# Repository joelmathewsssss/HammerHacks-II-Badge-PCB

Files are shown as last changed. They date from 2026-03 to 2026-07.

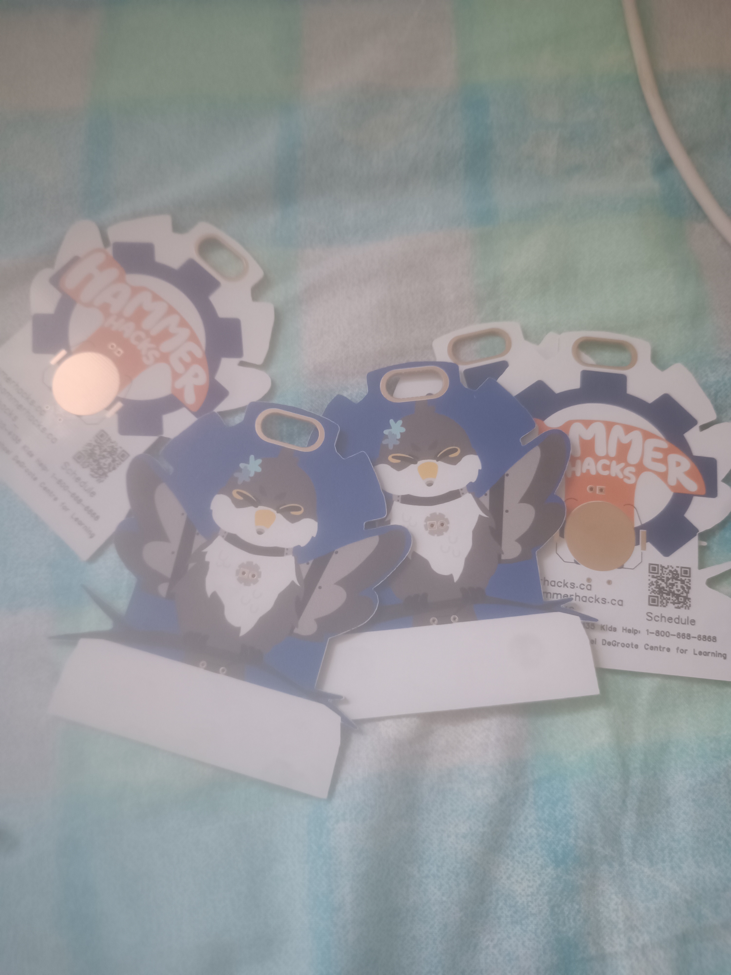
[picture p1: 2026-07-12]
assets/PICS/0ec4fcd7-279c-4da6-a28e-f8afc382110b.jpg

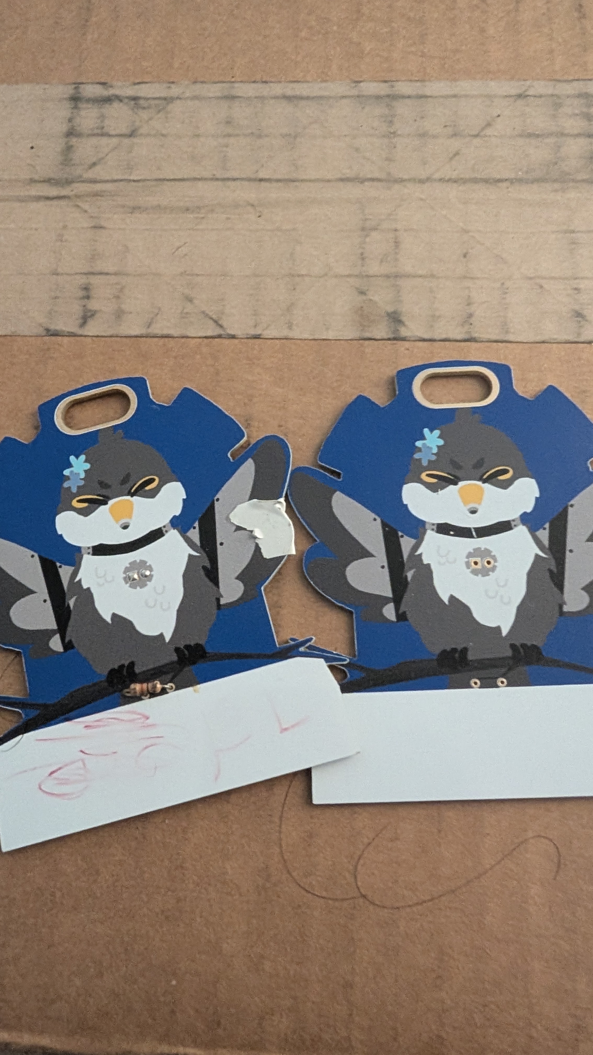
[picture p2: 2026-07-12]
assets/PICS/PXL_20260712_225921867.jpg

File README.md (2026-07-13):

# HammerHacks II Badge PCB

HammerHacks II Badge PCB

The official HammerHacks II Hacker Badge.
Made for Hackers to proudly show their name with HammerHacks swag.
Designed to be a soldering workshop to get students into hardware.
Simple PCB with LED circuit using coin battery. Includes Hackathon Info.







Demo Vid: https://drive.google.com/file/d/1kAkGNcVEJjuDBygq6s-vyhGiOASqDllP/view?usp=sharing

<table style="border-collapse: collapse; width: 100%; font-family: Arial, sans-serif; font-size: 14px">
  <thead>
    <tr>
      <th style="background-color: #f1f5f9; color: #1e293b; text-align: left; padding: 8px; font-weight: bold; border: 1px solid #e2e8f0">Name</th>
      <th style="background-color: #f1f5f9; color: #1e293b; text-align: left; padding: 8px; font-weight: bold; border: 1px solid #e2e8f0">Purpose</th>
      <th style="background-color: #f1f5f9; color: #1e293b; text-align: left; padding: 8px; font-weight: bold; border: 1px solid #e2e8f0">Quantity</th>
      <th style="background-color: #f1f5f9; color: #1e293b; text-align: left; padding: 8px; font-weight: bold; border: 1px solid #e2e8f0">Total Cost (USD)</th>
      <th style="background-color: #f1f5f9; color: #1e293b; text-align: left; padding: 8px; font-weight: bold; border: 1px solid #e2e8f0">Link</th>
      <th style="background-color: #f1f5f9; color: #1e293b; text-align: left; padding: 8px; font-weight: bold; border: 1px solid #e2e8f0">Distributor</th>
    </tr>
  </thead>
  <tbody>
    <tr>
      <td style="color: #334155; text-align: left; padding: 8px; border: 1px solid #e2e8f0">PCB Badge</td>
      <td style="color: #334155; text-align: left; padding: 8px; border: 1px solid #e2e8f0">Badge</td>
      <td style="color: #334155; text-align: left; padding: 8px; border: 1px solid #e2e8f0">1</td>
      <td style="color: #334155; text-align: left; padding: 8px; border: 1px solid #e2e8f0">8.39</td>
      <td style="color: #334155; text-align: left; padding: 8px; border: 1px solid #e2e8f0"></td>
      <td style="color: #334155; text-align: left; padding: 8px; border: 1px solid #e2e8f0">JLC PCB</td>
    </tr>
    <tr>
      <td style="color: #334155; text-align: left; padding: 8px; border: 1px solid #e2e8f0">Resistor</td>
      <td style="color: #334155; text-align: left; padding: 8px; border: 1px solid #e2e8f0">limit current</td>
      <td style="color: #334155; text-align: left; padding: 8px; border: 1px solid #e2e8f0">1</td>
      <td style="color: #334155; text-align: left; padding: 8px; border: 1px solid #e2e8f0">0.00</td>
      <td style="color: #334155; text-align: left; padding: 8px; border: 1px solid #e2e8f0"></td>
      <td style="color: #334155; text-align: left; padding: 8px; border: 1px solid #e2e8f0">Have</td>
    </tr>
    <tr>
      <td style="color: #334155; text-align: left; padding: 8px; border: 1px solid #e2e8f0">Battery:BatteryHolder_Keystone_3034_1x20mm</td>
      <td style="color: #334155; text-align: left; padding: 8px; border: 1px solid #e2e8f0"></td>
      <td style="color: #334155; text-align: left; padding: 8px; border: 1px solid #e2e8f0">1</td>
      <td style="color: #334155; text-align: left; padding: 8px; border: 1px solid #e2e8f0">4.95</td>
      <td style="color: #334155; text-align: left; padding: 8px; border: 1px solid #e2e8f0">https://www.amazon.ca/Qsvbeeqj-Battery-Retainer-Surface-Soldrable/dp/B0FLXHY725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</td>
      <td style="color: #334155; text-align: left; padding: 8px; border: 1px solid #e2e8f0">Amazon</td>
    </tr>
    <tr>
      <td style="color: #334155; text-align: left; padding: 8px; border: 1px solid #e2e8f0">Blue LED</td>
      <td style="color: #334155; text-align: left; padding: 8px; border: 1px solid #e2e8f0"></td>
      <td style="color: #334155; text-align: left; padding: 8px; border: 1px solid #e2e8f0">1</td>
      <td style="color: #334155; text-align: left; padding: 8px; border: 1px solid #e2e8f0">1.95</td>
      <td style="color: #334155; text-align: left; padding: 8px; border: 1px solid #e2e8f0">https://www.amazon.ca/100PCS-Superbright-5mm-Round-Light/dp/B00ME76D0I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</td>
      <td style="color: #334155; text-align: left; padding: 8px; border: 1px solid #e2e8f0">Amazon</td>
    </tr>
  </tbody>
</table>
Credits to Rosan Syal for making the design and Merinel Gomez for creating the assets!

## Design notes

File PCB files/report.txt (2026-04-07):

Plotted to 'C:\Users\joela\Documents\GitHub\HammerHacks II Badge PCB\PCB files\fab\HammerHacks II Badge PCB-F_Cu.gbr'.
Plotted to 'C:\Users\joela\Documents\GitHub\HammerHacks II Badge PCB\PCB files\fab\HammerHacks II Badge PCB-B_Cu.gbr'.
Plotted to 'C:\Users\joela\Documents\GitHub\HammerHacks II Badge PCB\PCB files\fab\HammerHacks II Badge PCB-F_Paste.gbr'.
Plotted to 'C:\Users\joela\Documents\GitHub\HammerHacks II Badge PCB\PCB files\fab\HammerHacks II Badge PCB-B_Paste.gbr'.
Plotted to 'C:\Users\joela\Documents\GitHub\HammerHacks II Badge PCB\PCB files\fab\HammerHacks II Badge PCB-F_Silkscreen.gbr'.
Plotted to 'C:\Users\joela\Documents\GitHub\HammerHacks II Badge PCB\PCB files\fab\HammerHacks II Badge PCB-B_Silkscreen.gbr'.
Plotted to 'C:\Users\joela\Documents\GitHub\HammerHacks II Badge PCB\PCB files\fab\HammerHacks II Badge PCB-F_Mask.gbr'.
Plotted to 'C:\Users\joela\Documents\GitHub\HammerHacks II Badge PCB\PCB files\fab\HammerHacks II Badge PCB-B_Mask.gbr'.
Plotted to 'C:\Users\joela\Documents\GitHub\HammerHacks II Badge PCB\PCB files\fab\HammerHacks II Badge PCB-Edge_Cuts.gbr'.
Created Gerber job file 'C:\Users\joela\Documents\GitHub\HammerHacks II Badge PCB\PCB files\fab\HammerHacks II Badge PCB-job.gbrjob'.
Info: Done.

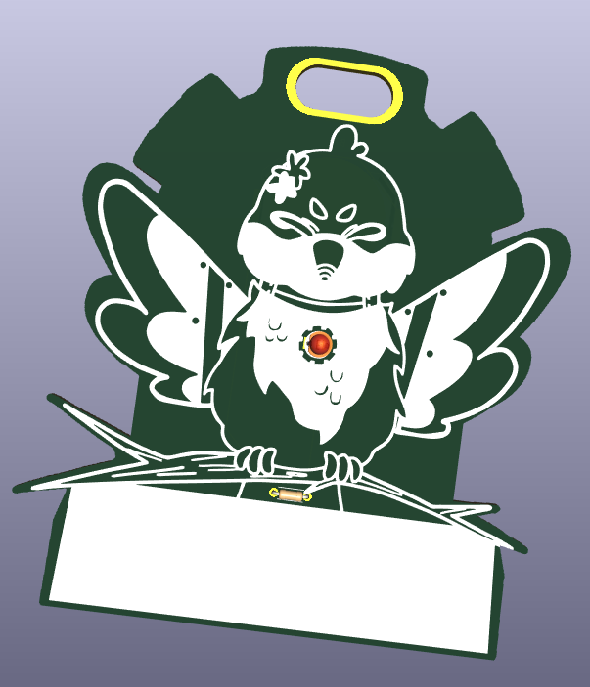
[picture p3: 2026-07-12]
assets/PICS/Screenshot 2026-03-18 171457.png

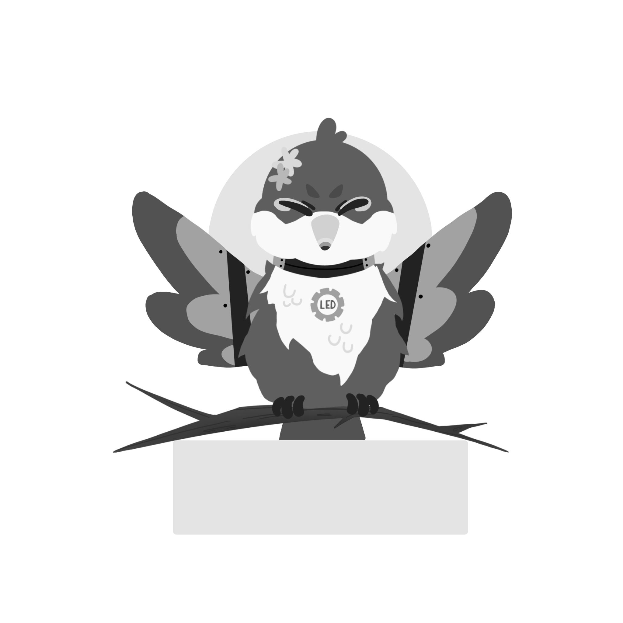
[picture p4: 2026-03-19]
assets/full.png

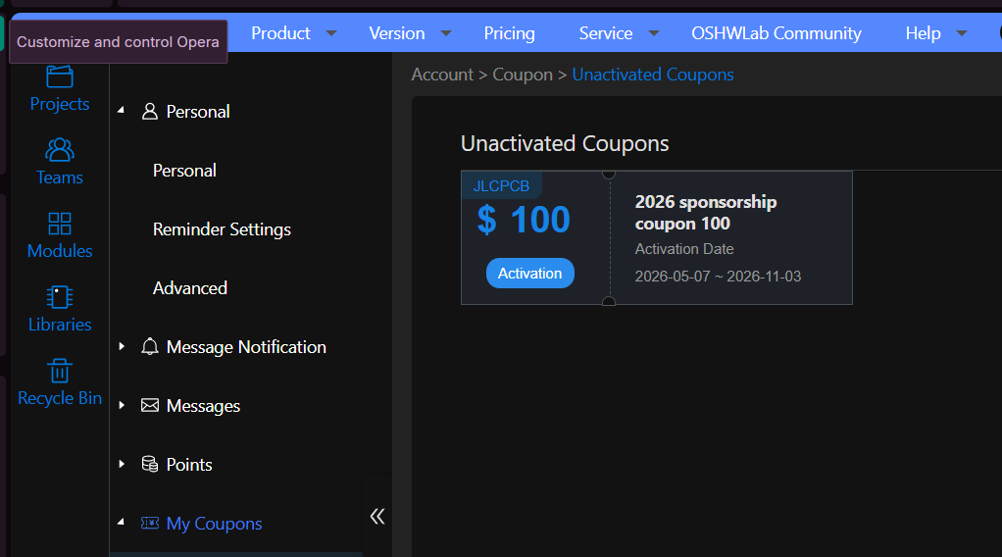
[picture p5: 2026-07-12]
assets/PICS/Screenshot 2026-05-07 062919.png

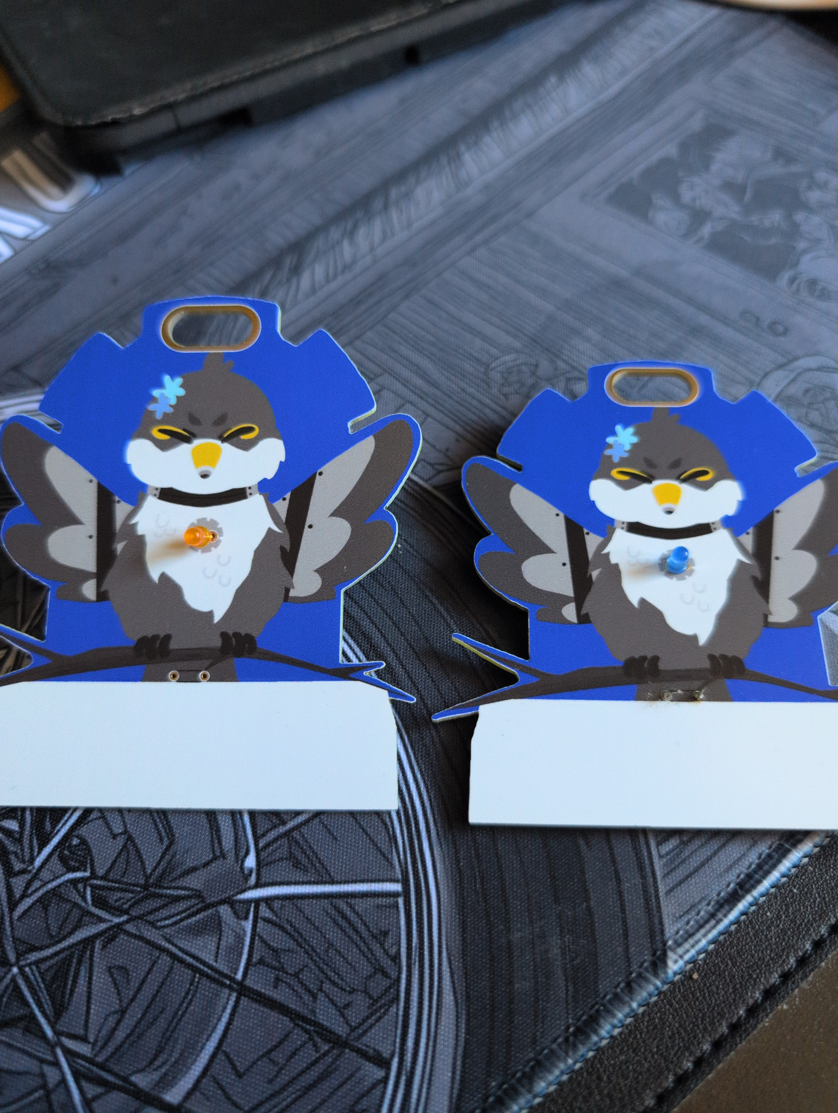
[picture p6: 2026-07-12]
assets/PICS/30e5c870-7722-40ba-a2bb-0e20258b65ed.jpg

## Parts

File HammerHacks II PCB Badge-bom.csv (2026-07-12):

Name | Purpose | Quantity | Total Cost (USD) | Link | Distributor
PCB Badge | Badge | 1 | 8.39 |  | JLC PCB
Resistor | limit current | 1 | 0.00 |  | Have
Battery:BatteryHolder_Keystone_3034_1x20mm |  | 1 | 4.95 | https://www.amazon.ca/Qsvbeeqj-Battery-Retainer-Surface-Soldrable/dp/B0FLXHY725 | Amazon
Blue LED |  | 1 | 1.95 | https://www.amazon.ca/100PCS-Superbright-5mm-Round-Light/dp/B00ME76D0I?adgrpid=1357897093534873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 | Amazon

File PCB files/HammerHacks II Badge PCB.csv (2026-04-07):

Value | Footprint | Qty | Cost | Link
Battery | Battery:BatteryHolder_Keystone_3034_1x20mm | 1 | 6.89 | https://www.amazon.ca/Qsvbeeqj-Battery-Retainer-Surface-Soldrable/dp/B0FLXHY725
LED | LED_THT:LED_D3.0mm | 1 | 2.72 | https://www.amazon.ca/100PCS-Superbright-5mm-Round-Light/dp/B00ME76D0I?adgrpid=1357897093534873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

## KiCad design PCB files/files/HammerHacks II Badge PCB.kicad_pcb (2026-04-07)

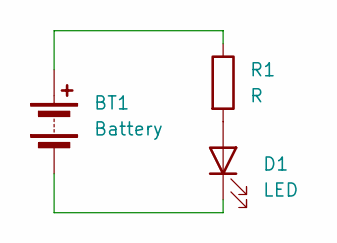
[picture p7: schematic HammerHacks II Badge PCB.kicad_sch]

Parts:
BT1: Battery; BatteryHolder_Keystone_3034_1x20mm
D1: LED; LED_D3.0mm
R1: R; R_Axial_DIN0204_L3.6mm_D1.6mm_P5.08mm_Horizontal

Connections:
unnamed: BT1.1 (+), R1.1
unnamed: BT1.2 (-), D1.1 (K)
unnamed: D1.2 (A), R1.2

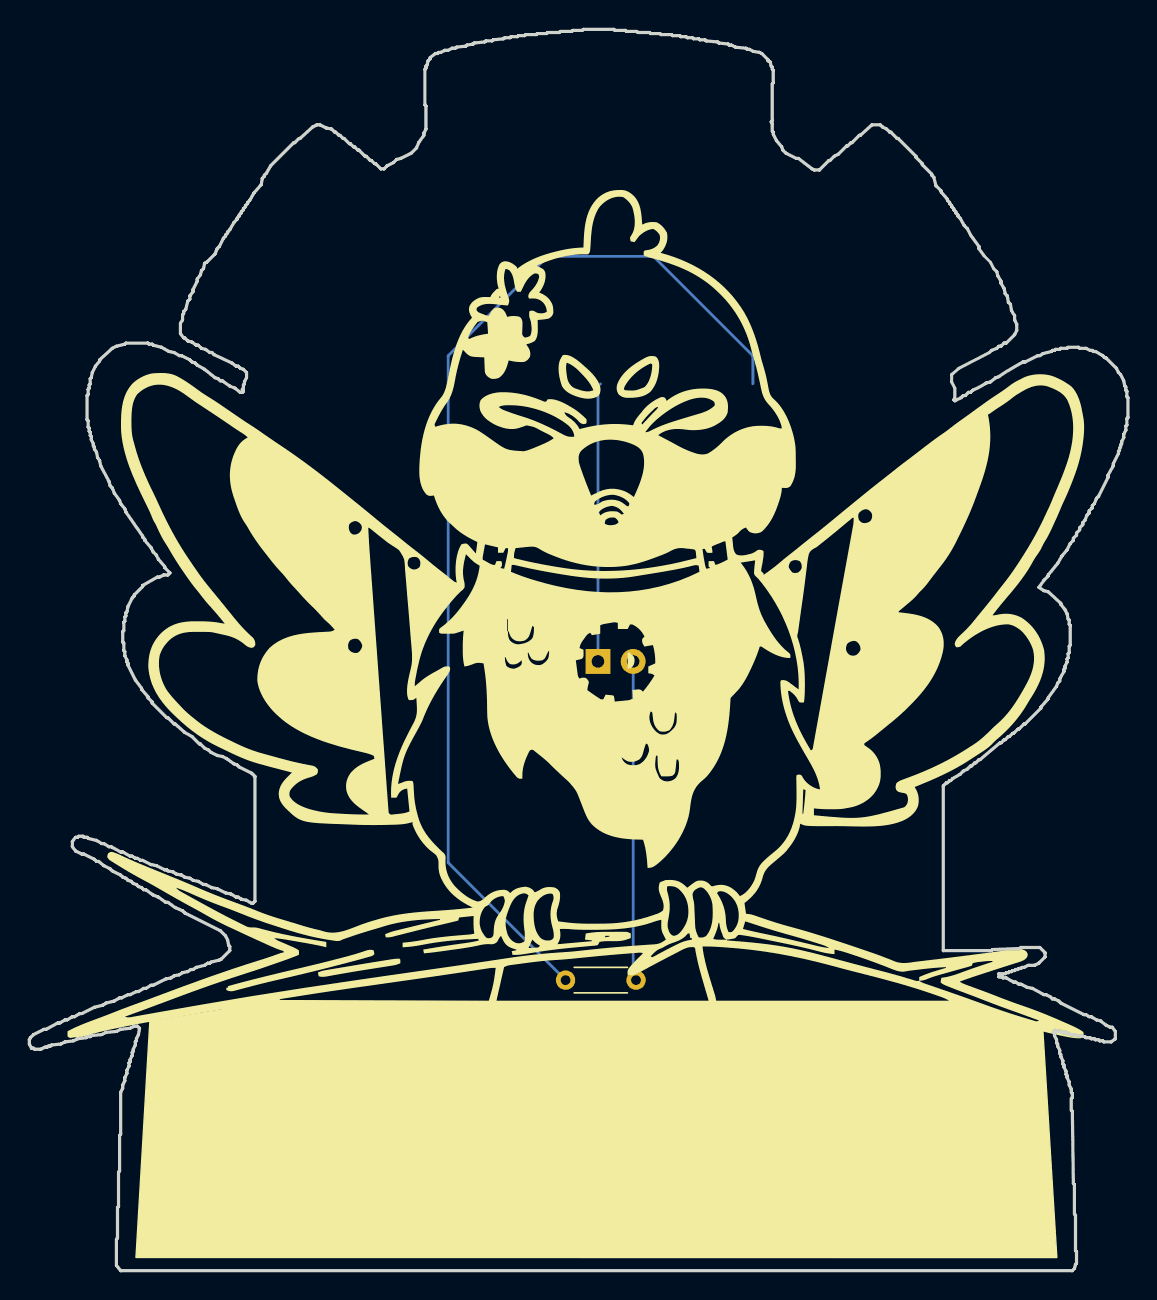
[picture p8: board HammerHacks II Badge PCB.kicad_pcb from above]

Board: 2 copper layers, 79.2 x 89.5 mm, 3 parts (1 on the bottom side), 3 nets.

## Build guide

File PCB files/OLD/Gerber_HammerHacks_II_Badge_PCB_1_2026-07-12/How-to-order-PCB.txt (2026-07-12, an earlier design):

How to Order PCB

Please refer to:
https://prodocs.easyeda.com/en/pcb/order-order-pcb/index.html

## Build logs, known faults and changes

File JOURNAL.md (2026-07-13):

<!--
  This journal is auto generated by Stasis.
-->
# Total Time Spent: 18.5h

# 7/12/2026 11 PM - Soldering up and Finishing V2

_Time spent: 0.1666666666666667h_

Finally soldered up the badge and it works!

I dont have side cutters so the wires are a bit choppy. 








# 7/12/2026 11 PM - Updating PCB for V2

_Time spent: 2.066666666666667h_

Fixed all issues identified in v1

I:

- Scaled the bird down and repositioned
- Made lanyard hole shorter
- Changed footprint to horizontal
- Changed name area slikscreen bounds
- Adjusted rear logo size and scale
- Changed CR2032 battery holder orientation for easy access
- Resized and reformated text and icons
- Fixed routing to be wired correctly

In addition, added sponsor logos to fuffil sponsorship goals










# 7/12/2026 11 PM - Soldering the first time and testing

_Time spent: 1h_

Soldered the components together.

Found that there were issues:

- Bird not centered and cut off
- Lanyard hole was too big
- Resistor Footprint was for vertical and not horizontal
- Name writing area silkscreen was too tall and cutoff tail
- Rear Logo was too big and wide
- Text was too congested and icons too thick

Most importantly, Easy EDA routed through the battery pad contacts (something I've never experienced before on KiCad), causing a short circuit that would stop the circuit from working.





30e5c870-7722-40ba-a2bb-0e20258b65ed

0ec4fcd7-279c-4da6-a28e-f8afc382110b






# 4/7/2026 2 PM - Converting to Easy EDA

_Time spent: 4.733333333333333h_

Due to sponsorship request from JLCPCB/Easy EDA, in order to get pcb discount, the pcb design had to be processed through Easy EDA Pro and use their multicolour silkscreen technology.

So I imported my KiCad project into Easy EDA and tried to fix things. I spent alot of time figuring out how to use Easy EDA as it was my first time. Spent a bunch of time trying to fix the silkscreen before I learned I could just import images.

So, I added some colour to the images, imported them, formatted the objects and added a few details (like qr code of schedule) and fixes on the back.

Spent time going through the fabrication process.











# 3/19/2026 4 AM - Grinding out Design Onto PCB

_Time spent: 6h_

Watch the timelapse instead- https://lapse.hackclub.com/timelapse/TLW3UozBr5oJ

Transformed design outline into edgecut
It was alot faster this time from the practice and learning from making a rough design, I knew how to use the online tools and where it breaks (see where I manually have to fix the edgecut)

Added design silk screen

Changed led from neopixel to normal and circuit to only have one LED.
Talked with the team and we decided to change to normal leds, as they look better and are easier to solder. I also spent alot of time looking at components, for what to order, how much it costs to order in bulk (since these badges will be for hackathon participants (about 150))

If youre making a PCB design, please get the Transformit plugin, (https://openscopeproject.org/projects/transformit/) saves lives.

Added silkscreen area to write name.
At first it was too small (4.2x1.4cm), so I resized (using transformit) (to 6.7cm x 1.8 cm)

Made a hole footprint in badge to attatch lanyard.

Added front copper layer design highlights.
At first, I was really dumb and did it manually. Next time i just used ms paint to fill in sections.

Added title text with back copper layer
Tried a couple things with text and canva but it didnt really work so I just added the logo text (from when I made a rough design (yes it was useful!)) on the back

Added (then removed) team signatures to rear silkscreen

Added org, event and safety info to rear silkscreen.

Results:














# 3/18/2026 6 PM - Designing PCB rough (waiting for good)

_Time spent: 4.5h_

Circuit - Design simple LED circuit to start in new KiCad Project:



Footprints - doing research for potential parts for pcb badge and assigning footprints. Decided to power pcb with CR2032 coin battery, 220 Ω throughole resistors and SMD 0805 (2mm x 1.2mm) Blue for LEDs:



Making PCB - Took the most time since I had to figure out how to make a custom pcb edge cut. I started by trying to trace a refrence image but it was too off/took too much time. I decided to try png to svg converters, went through a couple different tools (https://www.freeconvert.com/png-to-svg,https://pdfaid.com/svg-to-dxf,https://convertio.co/svg-dxf/,https://www.ilovesvg.com/image-to-svg-outline) until I found the one (https://fiveko.com/online-tools/picture-outline/). I had to try a couple times before I got the right shape and outline. Had to fix the outline manually at some points of overlap or disconnection. Added logo text as copper layer as well using the same tools:







Routing - Routed connections from between connections, using a via to route from front layer LED to back layer battery pad.










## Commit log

2026-03-19 Pretty Much finished, waiting for final details. Some file managment
    https://lapse.hackclub.com/timelapse/TLW3UozBr5oJ
    [HammerHacks II Badge PCB.kicad_pcb, HammerHacks II Badge PCB.kicad_sch]
2026-04-07 easy eda update
    [BOM.csv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]
2026-04-07 del old bom
    [BOM.csv, HammerHacks II PCB Badge-bom.csv]
2026-07-13 Update images and description in README
    Removed old images and added new images related to the soldering workshop.
